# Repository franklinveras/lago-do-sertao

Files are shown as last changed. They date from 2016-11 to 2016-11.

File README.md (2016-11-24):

<h1>Projeto de Automação do Lago</h1>
Projeto simples de automação de um lago ornamental, com:
<ul>
    <li>Iluminação LED RGB submersa</li>
    <li>Duas bombas (uma para cascata e outra para filtros)</li>
    <li>Esterilizador UV</li>
    <li>Iluminação externa</li>
    <li>Controle das bombas</li>
    <li>Monitoramento de luminosidade</li>
    <li>Monitoramento de temperatura da água</li>
    <li>Navegação por menu utilizando um LCD 16x2, encoder e três botões.</li>
    <li>Controle por rádio nRF24l01+</li>
</ul>

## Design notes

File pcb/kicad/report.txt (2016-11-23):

Info: Reading netlist file "/home/franklin/Documentos/Automação do Lago/placa_principal/placa_principal.net".

Info: Using references to match components and footprints.

Info: Checking netlist component footprint "C1:/5677A3F7:Capacitors_ThroughHole:C_Radial_D5_L11_P2".

Info: Checking netlist component footprint "C2:/5677AE71:Capacitors_ThroughHole:C_Radial_D5_L11_P2".

Info: Checking netlist component footprint "C3:/5666238D:Capacitors_ThroughHole:C_Disc_D3_P2.5".

Info: Checking netlist component footprint "C4:/566623FB:Capacitors_ThroughHole:C_Disc_D3_P2.5".

Info: Checking netlist component footprint "D1:/5678EB42:LEDs:LED-3MM".

Info: Checking netlist component footprint "D2:/56796AAA:LEDs:LED-3MM".

Info: Checking netlist component footprint "D3:/5679722E:LEDs:LED-3MM".

Info: Checking netlist component footprint "D4:/56798478:LEDs:LED-3MM".

Info: Checking netlist component footprint "D5:/5669736B:Diodes_ThroughHole:Diode_DO-41_SOD81_Horizontal_RM10".

Info: Checking netlist component footprint "D6:/56796A75:Diodes_ThroughHole:Diode_DO-35_SOD27_Horizontal_RM10".

Info: Checking netlist component footprint "D7:/567971F9:Diodes_ThroughHole:Diode_DO-35_SOD27_Horizontal_RM10".

Info: Checking netlist component footprint "D8:/56798443:Diodes_ThroughHole:Diode_DO-35_SOD27_Horizontal_RM10".

Info: Checking netlist component footprint "DS1:/56666353:s@t_holes:SO16".

Info: Checking netlist component footprint "IC1:/56661118:Housings_DIP:DIP-28_W7.62mm_LongPads".

Info: Checking netlist component footprint "J1:/56698F89:Pin_Headers:Pin_Header_Straight_2x04".

Info: Checking netlist component footprint "M1:/5675F8E9:s@turnal:SIL-2".

Info: Checking netlist component footprint "M2:/5675FA5D:s@turnal:SIL-2".

Info: Checking netlist component footprint "M3:/567C84A4:s@turnal:SIL-4".

Info: Checking netlist component footprint "M4:/566E128A:s@turnal:SIL-2".

Info: Checking netlist component footprint "M5:/566F27DB:s@turnal:SIL-2".

Info: Checking netlist component footprint "M6:/566F2EC7:s@turnal:SIL-2".

Info: Checking netlist component footprint "M7:/566F7F09:Connect:bornier2".

Info: Checking netlist component footprint "M8:/566FC5B6:Connect:bornier2".

Info: Checking netlist component footprint "M9:/567462E9:Connect:bornier2".

Info: Checking netlist component footprint "M10:/5674630A:Connect:bornier2".

Info: Checking netlist component footprint "M11:/56755BDE:Connect:bornier3".

Info: Checking netlist component footprint "M12:/56698DE0:Connect:bornier2".

Info: Checking netlist component footprint "M13:/56796AA0:Connect:bornier2".

Info: Checking netlist component footprint "M14:/56797224:Connect:bornier2".

Info: Checking netlist component footprint "M15:/5679846E:Connect:bornier2".

Info: Checking netlist component footprint "M16:/566A2CB8:s@turnal:SIL-4".

Info: Checking netlist component footprint "M17:/567392D7:Connect:bornier2".

Info: Checking netlist component footprint "M18:/5678256F:Connect:bornier3".

Info: Checking netlist component footprint "Q1:/5667ABD5:TO_SOT_Packages_THT:TO-92_Inline_Wide".

Info: Checking netlist component footprint "Q2:/566A40EE:TO_SOT_Packages_THT:TO-220_Neutral123_Vertical_LargePads".

Info: Checking netlist component footprint "Q3:/566A4194:TO_SOT_Packages_THT:TO-220_Neutral123_Vertical_LargePads".

Info: Checking netlist component footprint "Q4:/5669FE29:TO_SOT_Packages_THT:TO-220_Neutral123_Vertical_LargePads".

Info: Checking netlist component footprint "Q5:/566978BF:TO_SOT_Packages_THT:TO-92_Inline_Wide".

Info: Checking netlist component footprint "Q6:/56796A8A:TO_SOT_Packages_THT:TO-92_Inline_Wide".

Info: Checking netlist component footprint "Q7:/5679720E:TO_SOT_Packages_THT:TO-92_Inline_Wide".

Info: Checking netlist component footprint "Q8:/56798458:TO_SOT_Packages_THT:TO-92_Inline_Wide".

Info: Checking netlist component footprint "R1:/566EA1D2:Resistors_ThroughHole:Resistor_Horizontal_RM10mm".

Info: Checking netlist component footprint "R2:/566F27E1:Resistors_ThroughHole:Resistor_Horizontal_RM10mm".

Info: Checking netlist component footprint "R3:/566F2ECD:Resistors_ThroughHole:Resistor_Horizontal_RM10mm".

Info: Checking netlist component footprint "R4:/56665ABE:Resistors_ThroughHole:Resistor_Horizontal_RM10mm".

Info: Checking netlist component footprint "R5:/566F7F0F:Resistors_ThroughHole:Resistor_Horizontal_RM10mm".

Info: Checking netlist component footprint "R6:/566FC5BC:Resistors_ThroughHole:Resistor_Horizontal_RM10mm".

Info: Checking netlist component footprint "R7:/5667B16D:Resistors_ThroughHole:Resistor_Horizontal_RM10mm".

Info: Checking netlist component footprint "R8:/567462EF:Resistors_ThroughHole:Resistor_Horizontal_RM10mm".

Info: Checking netlist component footprint "R9:/56746310:Resistors_ThroughHole:Resistor_Horizontal_RM10mm".

Info: Checking netlist component footprint "R10:/567197F7:Resistors_ThroughHole:Resistor_Horizontal_RM10mm".

Info: Checking netlist component footprint "R11:/567221FB:Resistors_ThroughHole:Resistor_Horizontal_RM10mm".

Info: Checking netlist component footprint "R12:/5673352E:Resistors_ThroughHole:Resistor_Horizontal_RM10mm".

Info: Checking netlist component footprint "R13:/5679103D:Resistors_ThroughHole:Resistor_Horizontal_RM10mm".

Info: Checking netlist component footprint "R14:/56796AB0:Resistors_ThroughHole:Resistor_Horizontal_RM10mm".

Info: Checking netlist component footprint "R15:/56797234:Resistors_ThroughHole:Resistor_Horizontal_RM10mm".

Info: Checking netlist component footprint "R16:/5679847E:Resistors_ThroughHole:Resistor_Horizontal_RM10mm".

Info: Checking netlist component footprint "R17:/5669847E:Resistors_ThroughHole:Resistor_Horizontal_RM10mm".

Info: Checking netlist component footprint "R18:/56796A99:Resistors_ThroughHole:Resistor_Horizontal_RM10mm".

Info: Checking netlist component footprint "R19:/5679721D:Resistors_ThroughHole:Resistor_Horizontal_RM10mm".

Info: Checking netlist component footprint "R20:/56798467:Resistors_ThroughHole:Resistor_Horizontal_RM10mm".

Info: Checking netlist component footprint "R21:/5677548F:Resistors_ThroughHole:Resistor_Horizontal_RM10mm".

Info: Checking netlist component footprint "R22:/5677407B:Resistors_ThroughHole:Resistor_Horizontal_RM10mm".

Info: Checking netlist component footprint "R23:/5673FB28:Resistors_ThroughHole:Resistor_Horizontal_RM10mm".

Info: Checking netlist component footprint "R24:/56766B65:Resistors_ThroughHole:Resistor_Horizontal_RM10mm".

Info: Checking netlist component footprint "REL1:/56696A34:s@turnal:RELAY-1RG".

Info: Checking netlist component footprint "REL2:/56796A6F:s@turnal:RELAY-1RG".

Info: Checking netlist component footprint "REL3:/567971F3:s@turnal:RELAY-1RG".

Info: Checking netlist component footprint "REL4:/5679843D:s@turnal:RELAY-1RG".

Info: Checking netlist component footprint "RV1:/566684F3:Resistors_ThroughHole:Resistor_Horizontal_RM10mm".

Info: Checking netlist component footprint "SW1:/56665F6E:Buttons_Switches_SMD:SW_SPST_EVPBF".

Info: Checking netlist component footprint "U1:/56778E15:TO_SOT_Packages_SMD:SOT-223".

Info: Checking netlist component footprint "U2:/56666699:Housings_DIP:DIP-16_W7.62mm_LongPads".

Info: Checking netlist component footprint "U3:/5668C6A5:Housings_DIP:DIP-16_W7.62mm_LongPads".

Info: Checking netlist component footprint "U4:/566E5D26:Housings_DIP:DIP-16_W7.62mm_LongPads".

Info: Checking netlist component footprint "Y1:/56661E21:Crystals:Crystal_HC49-U_Vertical".

Error: Component 'Q2' pad 'G' not found in footprint 'TO_SOT_Packages_THT:TO-220_Neutral123_Vertical_LargePads'

Error: Component 'Q2' pad 'D' not found in footprint 'TO_SOT_Packages_THT:TO-220_Neutral123_Vertical_LargePads'

Error: Component 'Q2' pad 'S' not found in footprint 'TO_SOT_Packages_THT:TO-220_Neutral123_Vertical_LargePads'

Error: Component 'Q3' pad 'G' not found in footprint 'TO_SOT_Packages_THT:TO-220_Neutral123_Vertical_LargePads'

Error: Component 'Q3' pad 'D' not found in footprint 'TO_SOT_Packages_THT:TO-220_Neutral123_Vertical_LargePads'

Error: Component 'Q3' pad 'S' not found in footprint 'TO_SOT_Packages_THT:TO-220_Neutral123_Vertical_LargePads'

Error: Component 'Q4' pad 'G' not found in footprint 'TO_SOT_Packages_THT:TO-220_Neutral123_Vertical_LargePads'

Error: Component 'Q4' pad 'D' not found in footprint 'TO_SOT_Packages_THT:TO-220_Neutral123_Vertical_LargePads'

Error: Component 'Q4' pad 'S' not found in footprint 'TO_SOT_Packages_THT:TO-220_Neutral123_Vertical_LargePads'

Error: Component 'RV1' pad '3' not found in footprint 'Resistors_ThroughHole:Resistor_Horizontal_RM10mm'

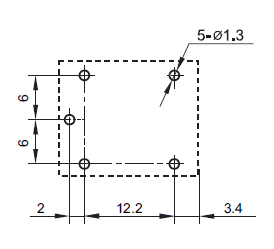
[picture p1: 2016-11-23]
datasheets/JQC-3FF_Pin_Layout.gif

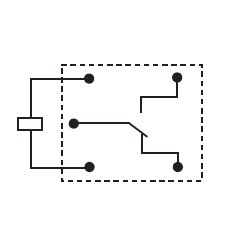
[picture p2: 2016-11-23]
datasheets/JQC-3FF_Circuit.gif

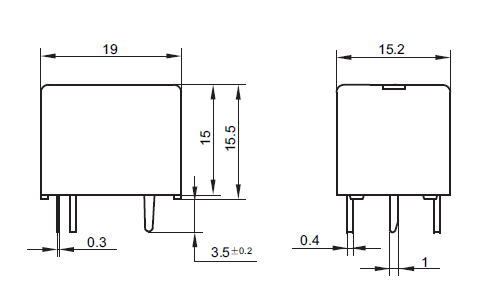
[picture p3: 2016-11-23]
datasheets/JQC-3FF_Dimensions.gif

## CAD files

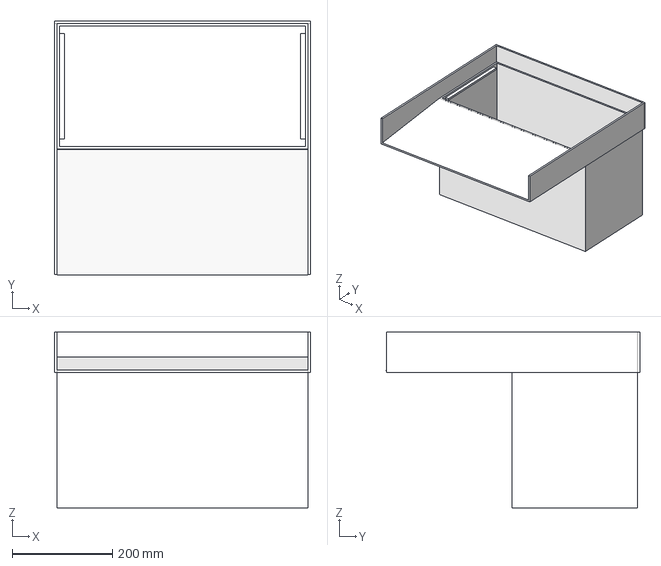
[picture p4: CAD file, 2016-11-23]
cascata/cascata.step
510.0 x 505.5 x 350.0 mm

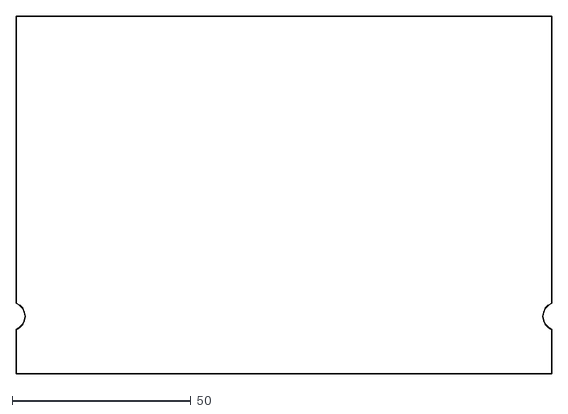
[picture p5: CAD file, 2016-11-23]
pcb/kicad/PCB_Outline_2.dxf
150.0 x 100.0

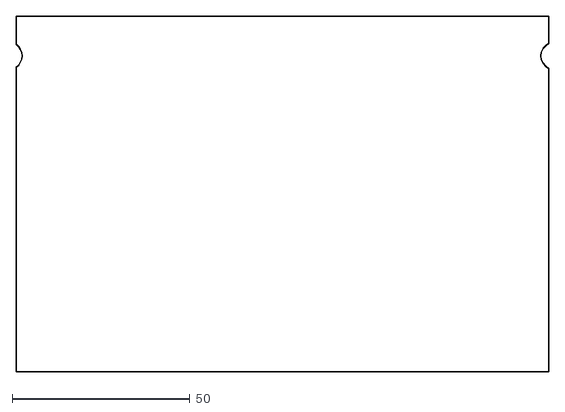
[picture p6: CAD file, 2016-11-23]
pcb/kicad/PCB_Outline.dxf
150.0 x 100.0

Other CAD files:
cascata/cascata.blend
cascata/cascata.fcstd
cascata/cascata.obj

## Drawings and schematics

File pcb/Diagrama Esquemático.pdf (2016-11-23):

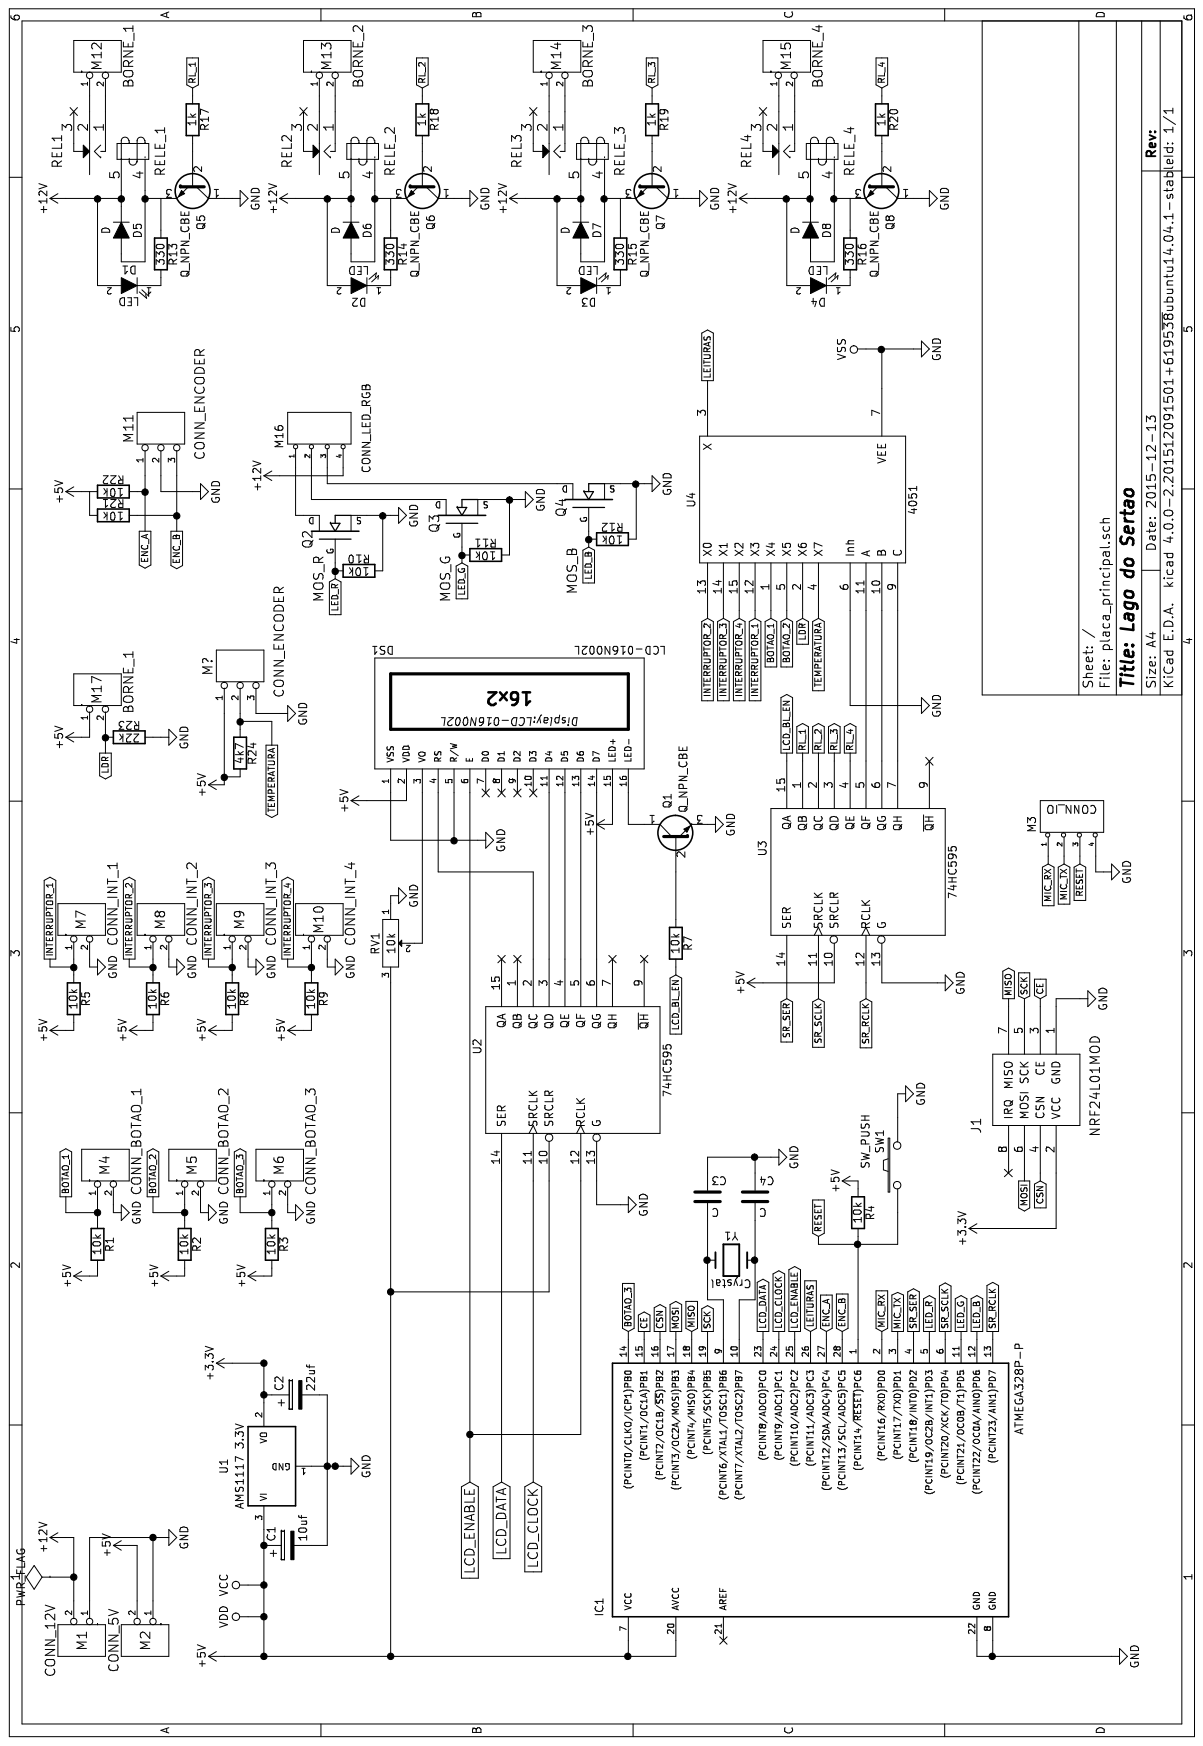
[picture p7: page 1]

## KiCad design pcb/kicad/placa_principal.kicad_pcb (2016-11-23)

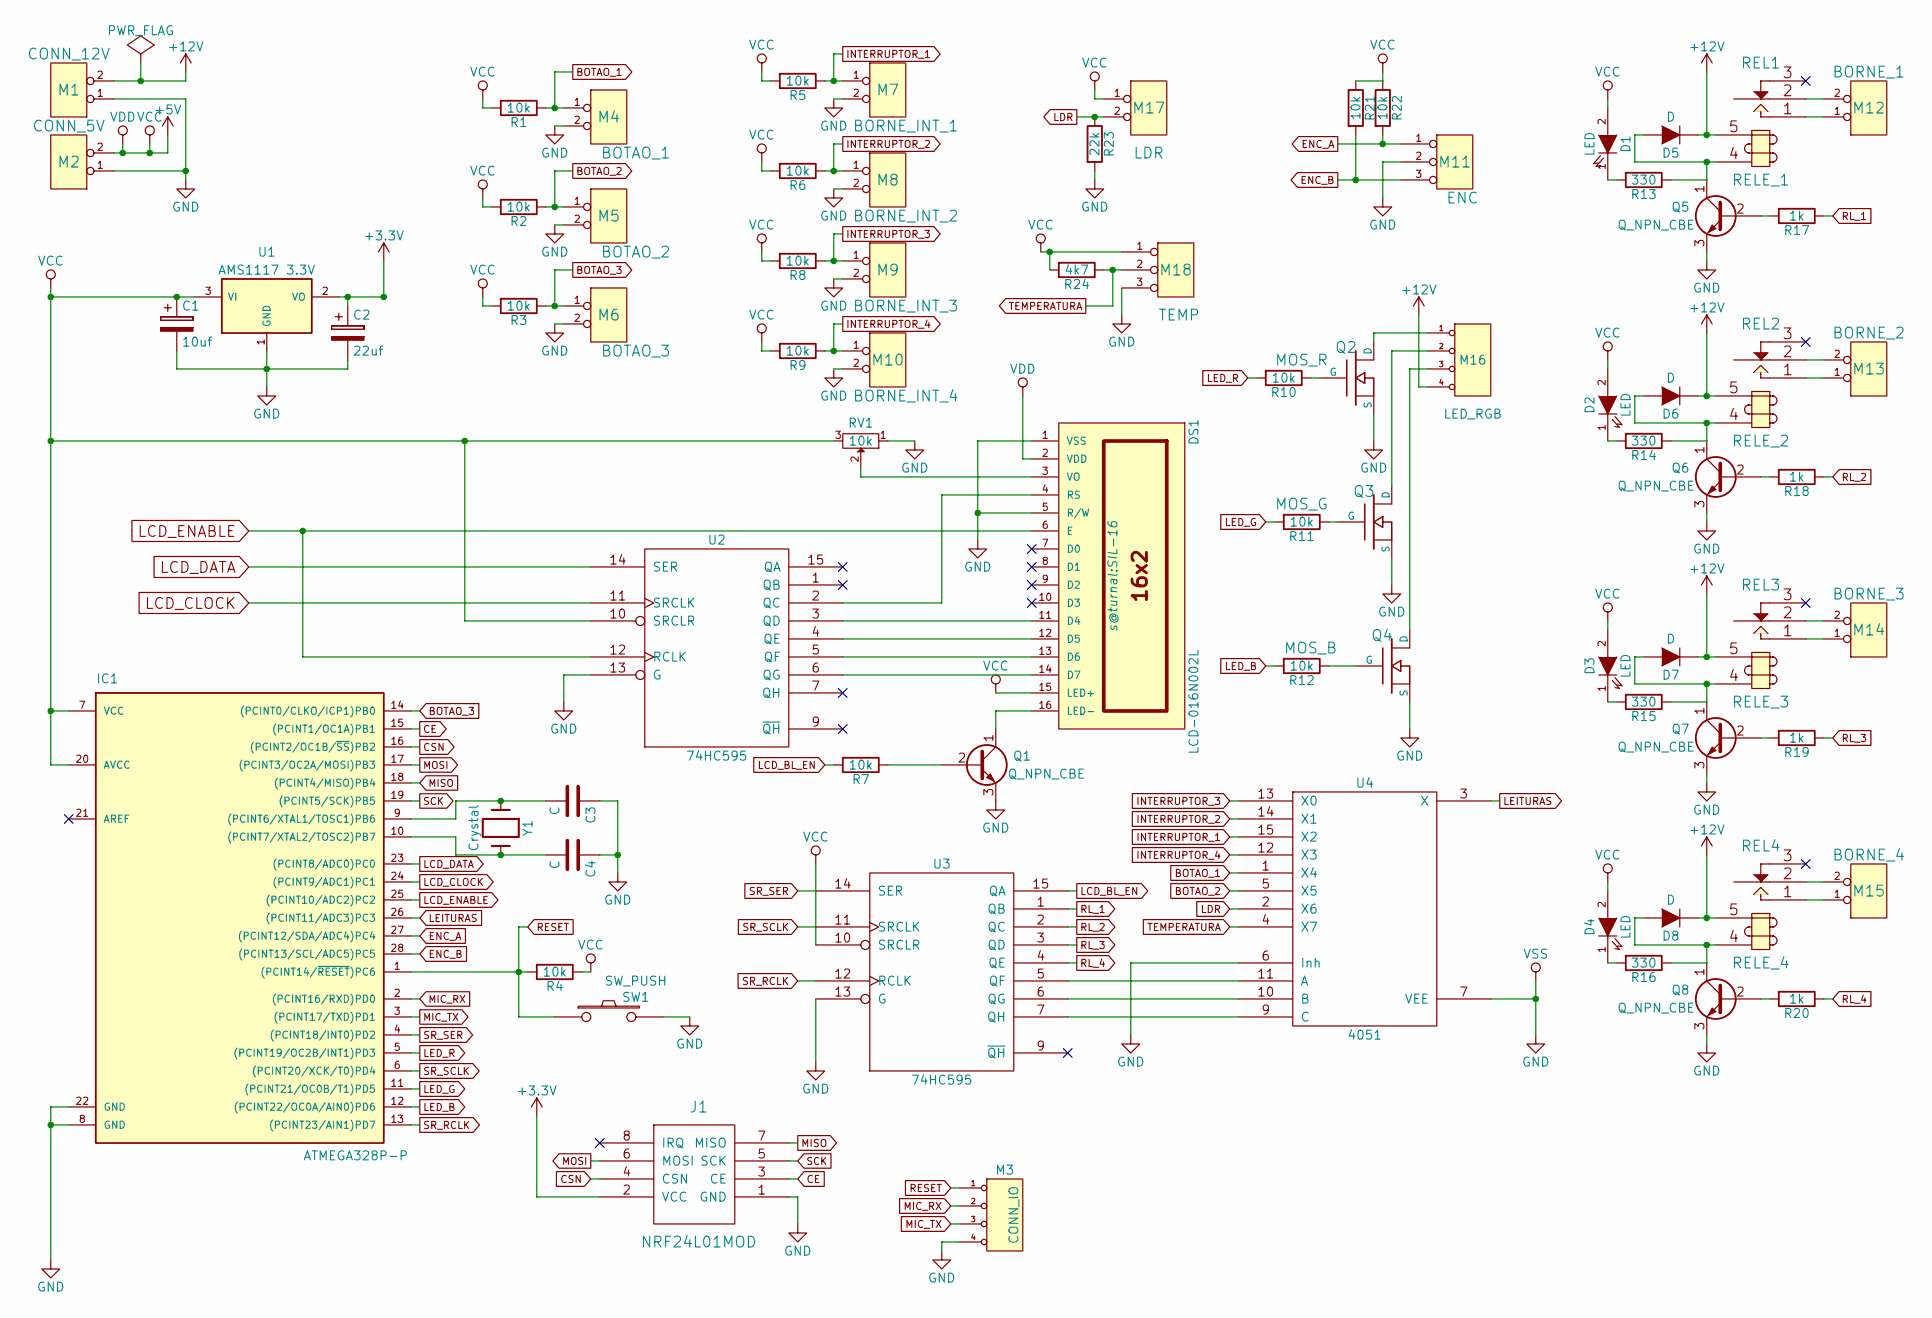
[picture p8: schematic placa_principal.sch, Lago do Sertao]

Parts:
C1: 10uf; C_Radial_D5_L11_P2
C2: 22uf; C_Radial_D5_L11_P2
C3, C4: C; C_Disc_D3_P2.5
D1, D2, D3, D4: LED; LED-3MM
D5, D6, D7, D8: D; Diode_DO-35_SOD27_Horizontal_RM10
DS1: LCD-016N002L; SIL-16
IC1: ATMEGA328P-P; DIP-28_W7.62mm_LongPads
J1: NRF24L01MOD; Pin_Header_Straight_2x04
M1: CONN_12V; SIL-2
M2: CONN_5V; SIL-2
M3: CONN_IO; SIL-4
M4: BOTAO_1; SIL-2
M5: BOTAO_2; SIL-2
M6: BOTAO_3; SIL-2
M7: BORNE_INT_1; bornier2
M8: BORNE_INT_2; bornier2
M9: BORNE_INT_3; bornier2
M10: BORNE_INT_4; bornier2
M11: ENC; SIL-3
M12: BORNE_1; bornier2
M13: BORNE_2; bornier2
M14: BORNE_3; bornier2
M15: BORNE_4; bornier2
M16: LED_RGB; bornier4
M17: LDR; bornier2
M18: TEMP; bornier3
Q1, Q5, Q6, Q7, Q8: Q_NPN_CBE; TO-92_Inline_Wide
Q2: MOS_R; TO220_GDS
Q3: MOS_G; TO220_GDS
Q4: MOS_B; TO220_GDS
R1, R2, R3, R4, R5, R6, R7, R8, R9, R10, R11, R12, R21, R22: 10k; Resistor_Horizontal_RM10mm
R13, R14, R15, R16: 330; Resistor_Horizontal_RM10mm
R17, R18, R19, R20: 1k; Resistor_Horizontal_RM10mm
R23: 22k; Resistor_Horizontal_RM10mm
R24: 4k7; Resistor_Horizontal_RM10mm
REL1: RELE_1; RELAY-1RG
REL2: RELE_2; RELAY-1RG
REL3: RELE_3; RELAY-1RG
REL4: RELE_4; RELAY-1RG
RV1: 10k; Potentiometer_Alps-RK163-single_15mm
SW1: SW_PUSH; SW_SPST_EVPBF
U1: AMS1117 3.3V; SOT-223
U2, U3: 74HC595; DIP-16_W7.62mm_LongPads
U4: 4051; DIP-16_W7.62mm_LongPads
Y1: Crystal; Crystal_HC49-U_Vertical

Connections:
+3V3: C2.1, J1.2 (VCC), U1.2 (VO)
+12V: D5.1 (K), D6.1 (K), D7.1 (K), D8.1 (K), M1.2, M16.4, REL1.5, REL2.5, REL3.5, REL4.5
BOTAO_1: M4.1, R1.1, U4.1 (X4)
BOTAO_2: M5.1, R2.1, U4.5 (X5)
BOTAO_3: IC1.14 ((PCINT0/CLKO/ICP1)PB0), M6.1, R3.1
CE: IC1.15 ((PCINT1/OC1A)PB1), J1.3 (CE)
CSN: IC1.16 ((PCINT2/OC1B/~SS~)PB2), J1.4 (CSN)
ENC_A: IC1.27 ((PCINT12/SDA/ADC4)PC4), M11.1, R22.2
ENC_B: IC1.28 ((PCINT13/SCL/ADC5)PC5), M11.3, R21.2
GND: C1.2, C2.2, C3.1, C4.1, DS1.1 (VSS), DS1.5 (R/W), IC1.8 (GND), IC1.22 (GND), J1.1 (GND), M1.1, M2.1, M3.4, M4.2, M5.2, M6.2, M7.2, M8.2, M9.2, M10.2, M11.2, M18.3, Q1.3 (E), Q2.S, Q3.S, Q4.S, Q5.3 (E), Q6.3 (E), Q7.3 (E), Q8.3 (E), R23.2, RV1.1, SW1.2, U1.1 (GND), U2.8 (GND), U2.13 (G), U3.8 (GND), U3.13 (G), U4.6 (Inh), U4.7 (VEE), U4.8 (VSS)
INTERRUPTOR_1: M7.1, R5.1, U4.15 (X2)
INTERRUPTOR_2: M8.1, R6.1, U4.14 (X1)
INTERRUPTOR_3: M9.1, R8.1, U4.13 (X0)
INTERRUPTOR_4: M10.1, R9.1, U4.12 (X3)
LCD_BL_EN: R7.2, U3.15 (QA)
LCD_CLOCK: IC1.24 ((PCINT9/ADC1)PC1), U2.11 (SRCLK)
LCD_DATA: IC1.23 ((PCINT8/ADC0)PC0), U2.14 (SER)
LCD_ENABLE: DS1.6 (E), IC1.25 ((PCINT10/ADC2)PC2), U2.12 (RCLK)
LDR: M17.2, R23.1, U4.2 (X6)
LED_B: IC1.12 ((PCINT22/OC0A/AIN0)PD6), R12.2
LED_G: IC1.11 ((PCINT21/OC0B/T1)PD5), R11.2
LED_R: IC1.5 ((PCINT19/OC2B/INT1)PD3), R10.2
LEITURAS: IC1.26 ((PCINT11/ADC3)PC3), U4.3 (X)
MIC_RX: IC1.2 ((PCINT16/RXD)PD0), M3.2
MIC_TX: IC1.3 ((PCINT17/TXD)PD1), M3.3
MISO: IC1.18 ((PCINT4/MISO)PB4), J1.7 (MISO)
MOSI: IC1.17 ((PCINT3/OC2A/MOSI)PB3), J1.6 (MOSI)
unnamed: C3.2, IC1.9 ((PCINT6/XTAL1/TOSC1)PB6), Y1.1
unnamed: C4.2, IC1.10 ((PCINT7/XTAL2/TOSC2)PB7), Y1.2
unnamed: D1.1 (K), R13.2
unnamed: D2.1 (K), R14.2
unnamed: D3.1 (K), R15.2
unnamed: D4.1 (K), R16.2
unnamed: D5.2 (A), Q5.1 (C), R13.1, REL1.4
unnamed: D6.2 (A), Q6.1 (C), R14.1, REL2.4
unnamed: D7.2 (A), Q7.1 (C), R15.1, REL3.4
unnamed: D8.2 (A), Q8.1 (C), R16.1, REL4.4
unnamed: DS1.3 (VO), RV1.2
unnamed: DS1.4 (RS), U2.2 (QC)
unnamed: DS1.11 (D4), U2.3 (QD)
unnamed: DS1.12 (D5), U2.4 (QE)
unnamed: DS1.13 (D6), U2.5 (QF)
unnamed: DS1.14 (D7), U2.6 (QG)
unnamed: DS1.16 (LED-), Q1.1 (C)
unnamed: M12.1, REL1.1 (T1)
unnamed: M12.2, REL1.2 (C1)
unnamed: M13.1, REL2.1 (T1)
unnamed: M13.2, REL2.2 (C1)
unnamed: M14.1, REL3.1 (T1)
unnamed: M14.2, REL3.2 (C1)
unnamed: M15.1, REL4.1 (T1)
unnamed: M15.2, REL4.2 (C1)
unnamed: M16.1, Q2.D
unnamed: M16.2, Q3.D
unnamed: M16.3, Q4.D
unnamed: Q1.2 (B), R7.1
unnamed: Q2.G, R10.1
unnamed: Q3.G, R11.1
unnamed: Q4.G, R12.1
unnamed: Q5.2 (B), R17.2
unnamed: Q6.2 (B), R18.2
unnamed: Q7.2 (B), R19.2
unnamed: Q8.2 (B), R20.2
unnamed: U3.5 (QF), U4.11 (A)
unnamed: U3.6 (QG), U4.10 (B)
unnamed: U3.7 (QH), U4.9 (C)
RESET: IC1.1 ((PCINT14/~RESET~)PC6), M3.1, R4.2, SW1.1
RL_1: R17.1, U3.1 (QB)
RL_2: R18.1, U3.2 (QC)
RL_3: R19.1, U3.3 (QD)
RL_4: R20.1, U3.4 (QE)
SCK: IC1.19 ((PCINT5/SCK)PB5), J1.5 (SCK)
SR_RCLK: IC1.13 ((PCINT23/AIN1)PD7), U3.12 (RCLK)
SR_SCLK: IC1.6 ((PCINT20/XCK/T0)PD4), U3.11 (SRCLK)
SR_SER: IC1.4 ((PCINT18/INT0)PD2), U3.14 (SER)
TEMPERATURA: M18.2, R24.1, U4.4 (X7)
VCC: C1.1, D1.2 (A), D2.2 (A), D3.2 (A), D4.2 (A), DS1.2 (VDD), DS1.15 (LED+), IC1.7 (VCC), IC1.20 (AVCC), M2.2, M17.1, M18.1, R1.2, R2.2, R3.2, R4.1, R5.2, R6.2, R8.2, R9.2, R21.1, R22.1, R24.2, RV1.3, U1.3 (VI), U2.10 (SRCLR), U2.16 (VCC), U3.10 (SRCLR), U3.16 (VCC), U4.16 (VDD)

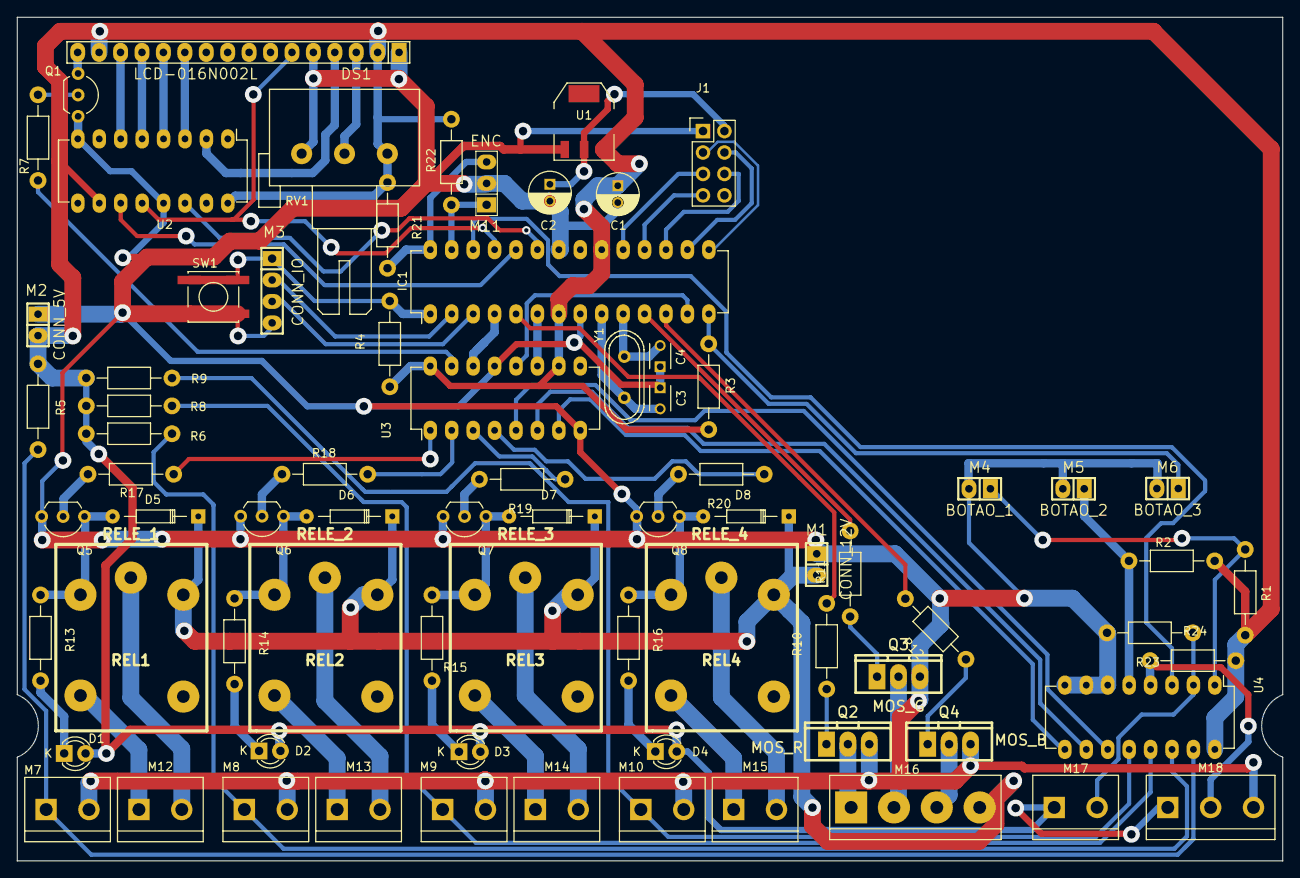
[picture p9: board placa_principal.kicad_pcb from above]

Board: 2 copper layers, 150.0 x 100.0 mm, 76 parts (0 on the bottom side), 77 nets.

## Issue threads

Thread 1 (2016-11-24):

Ligar/Desligar Filtro UV conforme as condições de iluminação

franklinveras, 2016-11-24:
O esterilizador UV consome energia, e não há necessidade de funcionar todo o tempo.
Ao reduzir a incidência de luz, a proliferação das algas é estabilizada, sendo um momento propício para o desligamento do filtro UV.

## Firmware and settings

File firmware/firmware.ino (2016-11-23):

#include <Arduino.h>
#include <LCD.h>
#include <LiquidCrystal_SR.h>
#include <RotaryEncoder.h>
#include <TimerOne.h>
#include <SPI.h>
#include "RF24.h"
#include "nRF24L01.h"

/* ---------- Mapa de pinos do ATMEGA238P-PU ---------- */

const char LED_R_PIN = 3;
const char LED_G_PIN = 5;
const char LED_B_PIN = 6;

const char SR_DATA_PIN = 2;
const char SR_CLOCK_PIN = 4;
const char SR_LATCH_PIN = 7;

const char BT3_PIN= 8;
const char RF_CE_PIN = 9;
const char RF_CSN_PIN = 10;

const char LCD_DATA_PIN = A0;
const char LCD_CLOCK_PIN = A1;
const char LCD_ENABLE_PIN = A2;

const char LEITURAS_PIN = A3;
const char ENC_A_PIN = A5;
const char ENC_B_PIN = A4;



/* --------------- Mapa de pinos do 74HC595 ---------------- */
char LCD_BL_PIN = 1;
char RELE1_PIN = 2;
char RELE2_PIN = 4;
char RELE3_PIN = 8;
char RELE4_PIN = 16;
char LTA_PIN = 32;
char LTB_PIN = 64;
char LTC_PIN = 128;

/* --------- Estado inicial dos pinos do 74HC595 ----------- */
unsigned char estados=0;
boolean tmp_state = false;

boolean lcd_bl_state = false;
boolean rele1_state = false;
boolean rele2_state= false;
boolean rele3_state = false;
boolean rele4_state = false;
boolean lta_state = false;
boolean ltb_state = false;
boolean ltc_state= false;

/* ------- Altera o estado de um pino do 74HC595 -------*/
void srWrite(boolean &variavel, boolean valor)
{

    variavel=valor;

    estados =
        ((lcd_bl_state)?LCD_BL_PIN:0)+
        ((rele1_state)?RELE1_PIN:0)+
        ((rele2_state)?RELE2_PIN:0)+
        ((rele3_state)?RELE3_PIN:0)+
        ((rele4_state)?RELE4_PIN:0)+
        ((lta_state)?LTA_PIN:0)+
        ((ltb_state)?LTB_PIN:0)+
        ((ltc_state)?LTC_PIN:0);

    digitalWrite(SR_LATCH_PIN, LOW);
    shiftOut(SR_DATA_PIN, SR_CLOCK_PIN, MSBFIRST, estados);
    digitalWrite(SR_LATCH_PIN, HIGH);
}

int srAnalogRead(char pino)
{
    lta_state = (pino & 1);
    ltb_state = (pino & 2);
    ltc_state = (pino & 4);
    srWrite(lta_state, lta_state); /* Atualiza o 74HC595 para escolher o pino de leitura no 4051 */

    return analogRead(LEITURAS_PIN);
}

int srDigitalRead(char pino)
{
    lta_state = (pino & 1);
    ltb_state = (pino & 2);
    ltc_state = (pino & 4);

    srWrite(lta_state, lta_state);

    return digitalRead(LEITURAS_PIN);
}

/* ------------------- Mapa de pinos do 4051 ------------------- */
char INT1_PIN = 2;
char INT2_PIN = 1;
char INT3_PIN = 0;
char INT4_PIN = 3;
char BT1_PIN = 4;
char BT2_PIN = 5;
char LDR_PIN = 6;
char TEMP_PIN = 7;

boolean int4_def_state;
boolean int4_state;

/* ---------------  Ininicialização das classes ----------------- */
LiquidCrystal_SR lcd(LCD_DATA_PIN, LCD_CLOCK_PIN, LCD_ENABLE_PIN);
RotaryEncoder encoder(ENC_A_PIN, ENC_B_PIN);
RF24 radio(9,10);
/* ----------------- Informações do nRF24l01 -------------------- */
unsigned char radio_mensagem[2];

/* ------------- Informações do display 16x2 ---------------- */
int lcd_bl_off_time=20000;
unsigned long lcd_atividade=0;
char Cx, Cy = 0;

/* ----------------- Funções do display 16x2 ------------------ */
void lcdClear()
{
    lcd.clear();
    Cx=0;
    Cy=0;
    lcd.setCursor(Cx,Cy);
}

void lcdPrint(char msg[])
{

    char i=0;
    while(msg[i])
    {
        lcd.setCursor(Cx,Cy);
        lcd.print(msg[i]);
        Cx++;
        if (Cx>15)Cy++;
        Cy%=2;
        Cx%=16;
        i++;
    }

}

/* ----------- Retardo no acionamento do Filtro UV ---------- */
boolean uv_liga = false;
unsigned long uv_delay = 30000;
unsigned long uv_acionamento = 0;


/* --------------- Informações da fita LED RGB -------------- */
const char LED_MODO_DESLIGADO = 0;
const char LED_MODO_FADE = 1;
const char LED_MODO_STROBE = 2;

const char LED_MODO_BRANCO = 3;
const char LED_MODO_VERMELHO = 4;
const char LED_MODO_LARANJA = 5;
const char LED_MODO_AMARELO = 6;
const char LED_MODO_VERDE = 7;
const char LED_MODO_CIANO = 8;
const char LED_MODO_AZUL_CLARO = 9;
const char LED_MODO_AZUL = 10;
const char LED_MODO_ROXO = 11;
const char LED_MODO_MARGENTA = 12;
const char LED_MODO_PERSONALIZADO= 13;
char LED_MODOS[14][17]=
{
    "   Desligado    ",
    "      Fade      ",
    "     Strobe     ",
    "     Branco     ",
    "    Vermelho    ",
    "    Laranja     ",
    "    Amarelo     ",
    "     Verde      ",
    "     Ciano      ",
    "   Azul Claro   ",
    "      Azul      ",
    "      Roxo      ",
    "    Margenta    ",
    "  Personalizado "
};

char led_modo = LED_MODO_DESLIGADO;
unsigned char led_brilho=255;
unsigned char led_r=0;
unsigned char led_g=0;
unsigned char led_b=0;
unsigned char led_velocidade=50;

unsigned char fade_seq[3][12]
{
    {255,255,255,127,0  ,0  ,0  ,0  ,0  ,127,255,255},
    {0  ,0  ,127,255,255,255,255,127,0  ,0  ,0  ,0  },
    {0  ,0  ,0  ,0  ,0  ,127,255,255,255,255,255,127}
};

unsigned char cor_seq[3][14]
{
/*   -   -   -   Bra Ver Lar Ama Ver Cia AzC Azu Rox Mar Per */
    {0  ,0  ,0  ,255,255,255,255,0  ,0  ,0  ,0  ,127,255,0  },
    {0  ,0  ,0  ,255,0  ,35 ,75 ,255,255,127,0  ,0  ,0  ,0  },
    {0  ,0  ,0  ,255,0  ,0  ,0  ,0  ,255,255,255,255,255,0  }
};

unsigned char fade_tmp[3][12];
unsigned char cor_tmp[3][14];


/* ----------------- Funções da fita LED RGB ---------------- */
void ledCor(unsigned char R, unsigned char G,unsigned char B)
{
    analogWrite(LED_R_PIN,R);
    analogWrite(LED_G_PIN,G);
    analogWrite(LED_B_PIN,B);
}

void ledMudaVelocidade(unsigned char velocidade)
{
    Timer1.initialize(30000-290*velocidade);
}

void ledMudaBrilho(unsigned char brilho)
{
    for (int x = 0; x!=3; x++)
    {

        for (int y = 0; y!=12; y++)
        {
            fade_tmp[x][y]=map(fade_seq[x][y],0,255,0,brilho);
        }

        for (int y = 0; y!=14; y++)
        {
            cor_tmp[x][y]=map(cor_seq[x][y],0,255,0,brilho);
        }
    }
}


void ledStep()
{
    static int i = 0;
    static int j = 0;

    if (led_modo==LED_MODO_DESLIGADO)
    {
        digitalWrite(LED_R_PIN,LOW);
        digitalWrite(LED_G_PIN,LOW);
        digitalWrite(LED_B_PIN,LOW);
    }
    else
    {

        j = i / 255;

        if(j>11)
        {
            i=0;
            j=0;
        }

        switch(led_modo)
        {
        case LED_MODO_FADE:
            if(j<11)
            {
                led_r = map(i-(j*255),0,255,fade_tmp[0][j],fade_tmp[0][j+1]);
                led_g = map(i-(j*255),0,255,fade_tmp[1][j],fade_tmp[1][j+1]);
                led_b = map(i-(j*255),0,255,fade_tmp[2][j],fade_tmp[2][j+1]);
                ledCor(led_r,led_g,led_b);
            }
            if(j==11)
            {
                led_r = map(i-(j*255),0,255,fade_tmp[0][j],fade_tmp[0][0]);
                led_g = map(i-(j*255),0,255,fade_tmp[1][j],fade_tmp[1][0]);
                led_b = map(i-(j*255),0,255,fade_tmp[2][j],fade_tmp[2][0]);
                ledCor(led_r,led_g,led_b);
            }

            break;

        case LED_MODO_STROBE:
            ledCor(fade_tmp[0][j],fade_tmp[1][j],fade_tmp[2][j]);
            break;

        default:
            ledCor(cor_tmp[0][led_modo],cor_tmp[1][led_modo],cor_tmp[2][led_modo]);
            break;

        }
        i++;
    }
}


/* ----------------------- Eventos ---------------------------*/

char enc_offset=0;

unsigned long BT_debounce_time=50;

unsigned long BT1_ldbtime=0;
boolean BT1_state;
boolean BT1_lstate=false;

unsigned long BT2_ldbtime=0;
boolean BT2_state;
boolean BT2_lstate=true;

unsigned long BT3_ldbtime=0;
boolean BT3_state;
boolean BT3_lstate=true;

const char EV_NULL = 0;
const char EV_ENCODER_CHANGE = 1;

const char EV_BT1_PRESS = 2;
const char EV_BT2_PRESS = 3;
const char EV_BT3_PRESS = 4;

const char EV_INT4_CHANGE = 5;

const char EV_RADIO_DUMP_MODO_LED = 6;
const char EV_RADIO_SET_MODO_LED = 7;
const char EV_RADIO_DUMP_BRILHO = 8;
const char EV_RADIO_SET_BRILHO = 9;
const char EV_RADIO_DUMP_VELOCIDADE = 10;
const char EV_RADIO_SET_VELOCIDADE = 11;

const char EV_RADIO_DUMP_LED_VERMELHO = 12;
const char EV_RADIO_SET_LED_VERMELHO = 13;

const char EV_RADIO_DUMP_LED_VERDE = 14;
const char EV_RADIO_SET_LED_VERDE = 15;

const char EV_RADIO_DUMP_LED_AZUL = 16;
const char EV_RADIO_SET_LED_AZUL = 17;

const char EV_RADIO_DUMP_RELE1 = 18;
const char EV_RADIO_SET_RELE1 = 19;

const char EV_RADIO_DUMP_RELE2 = 20;
const char EV_RADIO_SET_RELE2 = 21;

const char EV_RADIO_DUMP_RELE3 = 22;
const char EV_RADIO_SET_RELE3 = 23;

const char EV_RADIO_DUMP_RELE4 = 24;
const char EV_RADIO_SET_RELE4 = 25;

const char EV_RADIO_DUMP_TEMP = 26;
const char EV_RADIO_DUMP_LDR_STATE = 27;

const unsigned char FB_POS = 255;
const unsigned char FB_NEG = 127;

char mn_menu = 0;
char mn_tmp_menu = 0;
char mn_submenu=0;
char mn_tmp_submenu = 0;
char mn_valor=0;

void lcdPrintEstado(boolean estado)
{
    (estado)?lcdPrint("    Ligado  "):lcdPrint("   Desligado");
}

void evento(char cod = 0)
{
    if(cod>5)
    {
        radio.stopListening();

        switch(cod){

            case EV_RADIO_DUMP_MODO_LED:
                radio_mensagem[1]=led_modo;
            break;

            case EV_RADIO_SET_MODO_LED:
                led_modo=radio_mensagem[1];
                radio_mensagem[1]=FB_POS;
            break;

            case EV_RADIO_DUMP_BRILHO:
                radio_mensagem[1] = led_brilho;
            break;

            case EV_RADIO_SET_BRILHO:
                led_brilho = radio_mensagem[1];
                radio_mensagem[1]=FB_POS;
            break;

            case EV_RADIO_DUMP_VELOCIDADE:
                radio_mensagem[1]=led_velocidade;
            break;

            case EV_RADIO_SET_VELOCIDADE:
                led_velocidade = radio_mensagem[1];
                radio_mensagem[1]=FB_POS;
            break;

            case EV_RADIO_DUMP_LED_VERMELHO:
                radio_mensagem[1]=cor_tmp[0][13];
            break;

            case EV_RADIO_SET_LED_VERMELHO:
                cor_tmp[0][13]=radio_mensagem[1];
                radio_mensagem[1]=FB_POS;
            break;

            case EV_RADIO_DUMP_LED_VERDE:
                radio_mensagem[1]=cor_tmp[1][13];
            break;

            case EV_RADIO_SET_LED_VERDE:
                cor_tmp[1][13]=radio_mensagem[1];
                radio_mensagem[1]=FB_POS;
            break;

            case EV_RADIO_DUMP_LED_AZUL:
                radio_mensagem[1]=cor_tmp[2][13];
            break;

            case EV_RADIO_SET_LED_AZUL:
                cor_tmp[2][13]=radio_mensagem[1];
                radio_mensagem[1]=FB_POS;
            break;

            case EV_RADIO_DUMP_RELE1:
                radio_mensagem[1]=rele1_state;
            break;

            case EV_RADIO_SET_RELE1:
                srWrite(rele1_state, radio_mensagem[1]);
                radio_mensagem[1]=FB_POS;
            break;

            case EV_RADIO_DUMP_RELE2:
                radio_mensagem[1]=rele2_state;
            break;

            case EV_RADIO_SET_RELE2:
                srWrite(rele2_state, radio_mensagem[1]);
                radio_mensagem[1]=FB_POS;
            break;

            case EV_RADIO_DUMP_RELE3:
                radio_mensagem[1]=rele3_state;
            break;

            case EV_RADIO_SET_RELE3:
                srWrite(rele3_state, radio_mensagem[1]);
                 radio_mensagem[1]=FB_POS;
            break;

            case EV_RADIO_DUMP_RELE4:
                radio_mensagem[1]=rele4_state;
            break;

            case EV_RADIO_SET_RELE4:
                srWrite(rele4_state, radio_mensagem[1]);
                radio_mensagem[1]=FB_POS;
            break;

            case EV_RADIO_DUMP_TEMP:
            break;

            case EV_RADIO_DUMP_LDR_STATE:
            break;

        }

        radio.write(&radio_mensagem, sizeof(unsigned char)*2);
        radio.startListening();

    }

    lcd_atividade=millis();
    mn_tmp_menu=mn_menu;
    mn_tmp_submenu=mn_submenu;

    if (cod == EV_INT4_CHANGE)
    {
        srWrite(rele4_state, !rele4_state);
    }
    /* ----------------------------- Menus ------------------------------*/
    switch(mn_menu)
    {
    case 0:
        switch(mn_submenu)
        {
        case 0:
            if(cod==EV_NULL)
            {
                lcdClear();
                lcdPrint(" Lago do Sertao     Ver 1.1");
            }
            if (cod == EV_BT1_PRESS)
            {
                mn_menu=1;
                mn_submenu=0;
            }
            if (cod == EV_BT2_PRESS)
            {
                mn_menu=2;
                mn_submenu=2;
                mn_valor=1;
            }
            if (cod == EV_ENCODER_CHANGE)
            {
                mn_menu=2;
                mn_submenu=1;
                mn_valor=1;
            }
            break;
        }
        break;

    case 1:
        switch(mn_submenu)
        {
        case 0:
            if(cod==EV_NULL)
            {
                lcdClear();
                lcdPrint(" Liga / Desliga      Tomada");
            }

            if (cod == EV_BT2_PRESS)
            {
                mn_submenu++;
            }
            if (cod == EV_BT3_PRESS)
            {
                mn_menu--;
            }
            if (cod == EV_ENCODER_CHANGE)
            {
                if(enc_offset>0)mn_menu++;
            }
            break;

        case 1:

            if(mn_valor==0)
            {
                tmp_state=rele1_state;
                if(cod==EV_NULL)
                {
                    lcdClear();
                    lcdPrint("   Bomba de        Filtragem");
                }

                if (cod == EV_ENCODER_CHANGE)
                {
                    if(enc_offset>0)
                    {
                        mn_submenu=2;
                    }
                }

                if (cod == EV_BT2_PRESS)
                {
                    mn_valor=1;
                }

                if (cod == EV_BT3_PRESS)
                {
                    mn_submenu=0;
                }
            }
            else
            {
                lcdClear();
                lcdPrint("B. de Filtragem ");


                if (cod == EV_ENCODER_CHANGE)
                {

                    if(enc_offset>0)
                    {
                        srWrite(rele1_state,true);
                        uv_acionamento=millis();
                    }
                    else
                    {
                        srWrite(rele1_state,false);
                        srWrite(rele2_state,false);
                        uv_liga=false;
                    }
                }
                Cx=0;
                Cy=1;
                lcd.setCursor(Cx,Cy);
                lcdPrintEstado(rele1_state);

                if(cod == EV_BT2_PRESS)
                {
                    mn_valor=0;
                }

                if(cod == EV_BT3_PRESS)
                {
                    mn_valor=0;
                    srWrite(rele1_state, tmp_state);
                }
            }
            break;

        case 2:
            if(mn_valor==0)
            {
                tmp_state=rele2_state;
                if(cod==EV_NULL)
                {
                    lcdClear();
                    lcdPrint("     Filtro       Ultravioleta");
                }

                if (cod == EV_ENCODER_CHANGE)
                {
                    mn_submenu+=enc_offset;
                }

                if (cod == EV_BT2_PRESS)
                {
                    mn_valor=2;
                }
                if (cod == EV_BT3_PRESS)
                {
                    mn_submenu=0;
                }

            }
            else
            {
                lcdClear();
                lcdPrint("   Filtro UV");

                if (cod == EV_ENCODER_CHANGE)
                {

                    if(enc_offset>0)
                    {
                        if(rele1_state && (millis()-uv_acionamento>uv_delay))
                        {
                            uv_liga=true;
                        }
                    }
                    else
                    {
                        srWrite(rele2_state,false);
                    }
                }

                Cx=0;
                Cy=1;
                lcd.setCursor(Cx,Cy);
                lcdPrintEstado(uv_liga||rele2_state);

                if(cod == EV_BT2_PRESS)
                {
                    mn_valor=0;
                }

                if(cod == EV_BT3_PRESS)
                {
                    mn_valor=0;
                    srWrite(rele2_state, tmp_state);
                }
            }
            break;

        case 3:
            if(mn_valor==0)
            {
                if(cod==EV_NULL)
                {
                    lcdClear();
                    lcdPrint("    Cascata");
                }

                if (cod == EV_ENCODER_CHANGE)
                {
                    mn_submenu+=enc_offset;
                }

                if (cod == EV_BT2_PRESS)
                {
                    mn_valor=3;
                }
                if (cod == EV_BT3_PRESS)
                {
                    mn_submenu=0;
                }

            }
            else
            {
                lcdClear();
                lcdPrint("    Cascata");

                if (cod == EV_NULL)
                {
                    tmp_state=rele3_state;
                }

                if (cod == EV_ENCODER_CHANGE)
                {
                    if(enc_offset>0)
                    {
                        srWrite(rele3_state,true);
                    }
                    else
                    {
                        srWrite(rele3_state,false);
                    }
                }

                Cx=0;
                Cy=1;
                lcd.setCursor(Cx,Cy);
                lcdPrintEstado(rele3_state);

                if(cod == EV_BT2_PRESS)
                {
                    mn_valor=0;
                }

                if(cod == EV_BT3_PRESS)
                {
                    mn_valor=0;
                    srWrite(rele3_state, tmp_state);
                }
            }
            break;

        case 4:
            if(mn_valor==0)
            {
                if(cod==EV_NULL)
                {
                    lcdClear();
                    lcdPrint("   Iluminacao       Externa");
                }

                if (cod == EV_ENCODER_CHANGE)
                {
                    if(enc_offset<0)
                    {
                        mn_submenu=3;
                    }
                }
                if (cod == EV_BT2_PRESS)
                {
                    mn_valor=4;
                }
                if (cod == EV_BT3_PRESS)
                {
                    mn_submenu=0;
                }
            }
            else
            {
                lcdClear();
                lcdPrint("  Ilum Externa");

                if (cod == EV_NULL)
                {
                    tmp_state=rele1_state;
                }

                if (cod == EV_ENCODER_CHANGE)
                {

                    if(enc_offset>0)
                    {
                        srWrite(rele4_state,true);
                    }
                    else
                    {
                        srWrite(rele4_state,false);
                    }
                }

                Cx=0;
                Cy=1;
                lcd.setCursor(Cx,Cy);
                lcdPrintEstado(rele4_state);
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
void loop ()
{

    /* ----------------------------- Leituras ------------------------------*/

    /*  Leitura do encoder */
    while(radio.available())
    {
        radio.read(&radio_mensagem, sizeof(unsigned char) * 2);
        evento(radio_mensagem[0]);
    }

    /*  Leitura do encoder */
    static int enc_pos = 0;
    encoder.tick();
    int enc_new_pos = encoder.getPosition();

    if (enc_pos != enc_new_pos)
    {
        enc_offset = enc_new_pos - enc_pos;
        evento(EV_ENCODER_CHANGE);
        enc_pos = enc_new_pos;
    }

    /*  Leitura do botão de Menu */
    boolean reading = (srDigitalRead(BT1_PIN))?0:1;
    if(BT1_lstate!=reading)
    {
        BT1_ldbtime=millis();
    };

    if(millis()-BT1_ldbtime>BT_debounce_time)
    {
        if (BT1_state!=reading)
        {
            BT1_state = reading;
            if(BT1_state == false)
            {
                evento(EV_BT1_PRESS);
            }
        }

    }
    BT1_lstate = reading;


    /*  Leitura do botão Confirmar */
    reading = (srDigitalRead(BT2_PIN))?0:1;
    if(BT2_lstate!=reading)
    {
        BT2_ldbtime=millis();
    };

    if(millis()-BT2_ldbtime>BT_debounce_time)
    {
        if (BT2_state!=reading)
        {
            BT2_state = reading;
            if(BT2_state == false)
            {
                evento(EV_BT2_PRESS);
            }
        }

    }
    BT2_lstate = reading;

    /*  Leitura do botão Cancelar */
    reading = (digitalRead(BT3_PIN))?0:1;
    if(BT3_lstate!=reading)
    {
        BT3_ldbtime=millis();
    };

    if(millis()-BT3_ldbtime>BT_debounce_time)
    {
        if (BT3_state!=reading)
        {
            BT3_state = reading;
            if(BT3_state == false)
            {
                evento(EV_BT3_PRESS);
            }
        }

    }
    BT3_lstate = reading;

    /*  Leitura do interruptor da iluminação externa */
    int4_state = srDigitalRead(INT4_PIN);
    if (int4_def_state!=int4_state)
    {
        int4_def_state=int4_state;
        evento(EV_INT4_CHANGE);
    }

    /* Desliga a luz de fundo do display ao atingir o tempo limite */
    if (millis() - lcd_atividade>lcd_bl_off_time && lcd_bl_state)
    {
        srWrite(lcd_bl_state, false);
        mn_menu=0;
        mn_submenu=0;
        mn_valor=0;
        lcd.noBlink();
        evento(EV_NULL);
    }

    /* Liga o filtro UV ao atingir o tempo limite */
    if ((millis() - uv_acionamento>uv_delay) && uv_liga)
    {
        srWrite(rele2_state, true);
        uv_liga=false;
    }

}

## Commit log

2016-11-23 commit inicial
    [PCB_Outline.dxf, PCB_Outline_2.dxf, cascata.blend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]
2016-11-24 Removidos desenhos de filtro em duplicata
2016-11-24 Removidos arquivos temporários de compilação
